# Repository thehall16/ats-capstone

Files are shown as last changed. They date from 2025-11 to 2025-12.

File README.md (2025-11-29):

# ats-capstone

11/29/2025
still need to figure out what LCD to use./ Display (maybe LCD maybe a Uart serial port connection)

Moved Firmware to Keil to easily use stm32cubemx for hal librarys and pin configuration.

Getting accurate readings from ZMPT101B display currently via uart and puTTY terminal.

Daughter board is in waiting on one componet to fully assemble

Reworking main PCB may use nucleo board instead of standalone mcu due to time constraint
aswell as code being formatted for the nucleo currently.

May need a new 12v power supply the cheap ups scares me.

We're gonna need a bigger boat (AC side housing for isolation).

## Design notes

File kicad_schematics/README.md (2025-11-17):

Folder containing KiCad schematics and PCB design

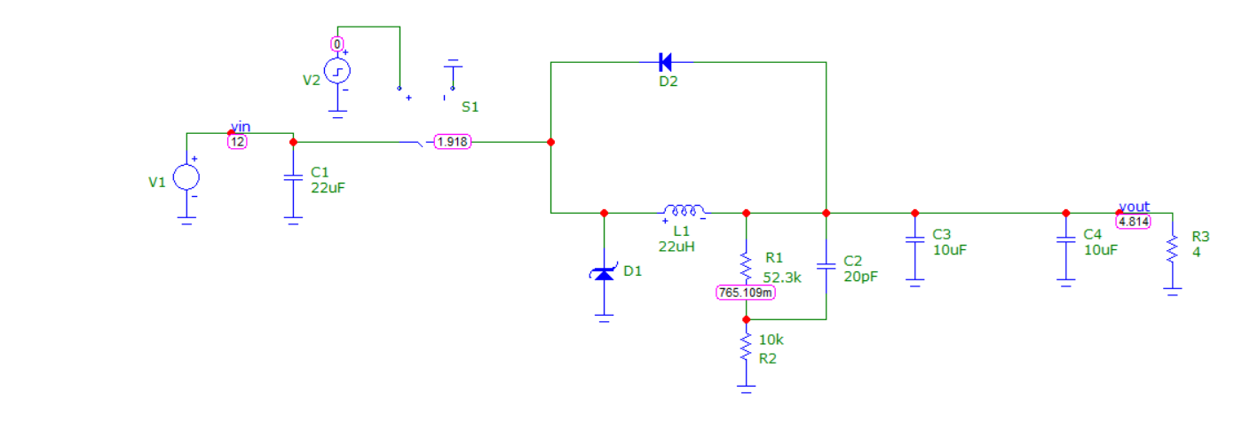
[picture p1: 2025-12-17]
bucksimsche.png

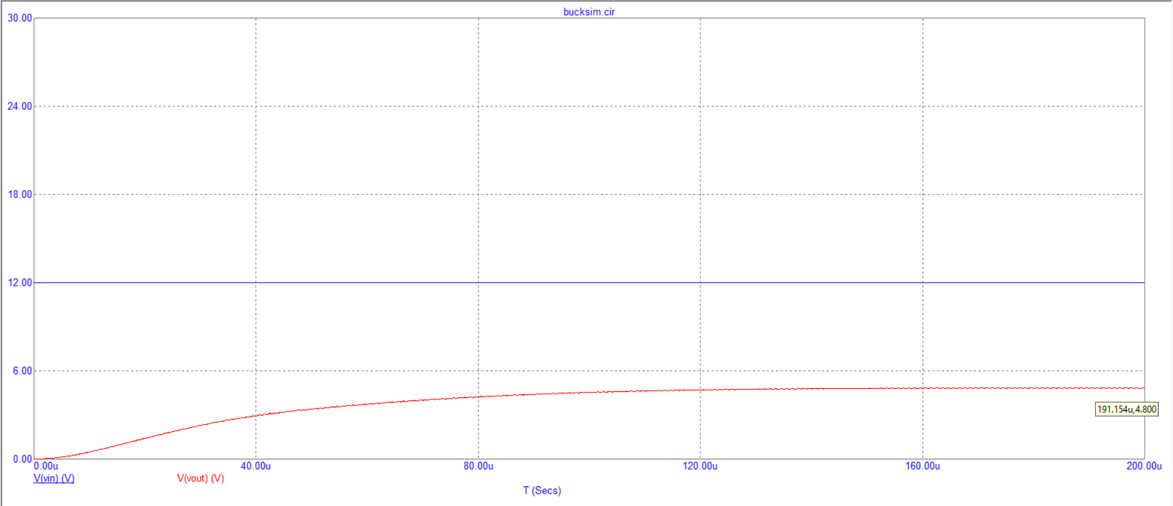
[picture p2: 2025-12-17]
bucksim.png

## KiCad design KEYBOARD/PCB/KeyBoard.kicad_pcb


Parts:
A1: RaspberryPi_Pico; RaspberryPi_Pico_Common_Unspecified
D1, D2, D3, D4, D5, D6, D7, D8, D9, D10, D11, D12, D13, D14, D15, D16, D17, D18, D19, D20, D21, D22, D23, D24, D25, D26, D27, D28, D29, D30, D31, D32, D33, D34, D35, D36, D37, D38, D39, D40, D41, D42, D43, D44, D45, D46, D47, D48, D49, D50, D51, D52, D53, D54, D55, D56, D57, D58, D59, D60, D61: 1N4148; D_DO-35_SOD27_P7.62mm_Horizontal
S1: MX_stab; STAB_MX_2u
S2, S3: MX_stab; STAB_MX_2.25u
S4: MX_stab; STAB_MX_2.75u
S5: MX_stab; STAB_MX_6.25u
SW1, SW2, SW3, SW4, SW5, SW6, SW7, SW8, SW9, SW10, SW11, SW12, SW13, SW16, SW17, SW18, SW19, SW20, SW21, SW22, SW23, SW24, SW25, SW26, SW27, SW30, SW31, SW32, SW33, SW34, SW35, SW36, SW37, SW38, SW39, SW40, SW51, SW52, SW53, SW54, SW55, SW56, SW57, SW58, SW59, SW60: SW_Push; SW_Cherry_MX_1.00u_PCB
SW14: SW_Push; SW_Cherry_MX_2.00u_PCB
SW15: SW_Push; SW_Cherry_MX_1.50u_PCB
SW28: SW_Push; SW_Cherry_MX_1.50u_Plate
SW29: SW_Push; SW_Cherry_MX_1.75u_PCB
SW41, SW50: SW_Push; SW_Cherry_MX_2.25u_PCB
SW42, SW43, SW44, SW46, SW48, SW49: SW_Push; SW_Cherry_MX_1.25u_PCB
SW45: SW_Push; SW_Cherry_MX_6.25u_PCB
SW47: SW_Push; SW_Cherry_MX_1.25u_Plate
SW61: SW_Push; SW_Cherry_MX_2.75u_PCB
SW62, SW63: RotaryEncoder_Switch_MP; RotaryEncoder_Alps_EC11E-Switch_Vertical_H20mm

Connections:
A1: A1.27 (GPIO21), SW62.A
A2: A1.32 (GPIO27_ADC1), SW63.A
B1: A1.29 (GPIO22), SW62.B
B2: A1.34 (GPIO28_ADC2), SW63.B
C0: A1.10 (GPIO7), SW1.1, SW15.1, SW29.1, SW42.1, SW50.1
C1: A1.11 (GPIO8), SW2.1, SW16.1, SW30.1, SW43.1, SW51.1
C2: A1.12 (GPIO9), SW3.1, SW17.1, SW31.1, SW44.1, SW52.1
C3: A1.14 (GPIO10), SW4.1, SW18.1, SW32.1, SW53.1
C4: A1.15 (GPIO11), SW5.1, SW19.1, SW33.1, SW54.1
C5: A1.16 (GPIO12), SW6.1, SW20.1, SW34.1, SW45.1, SW55.1
C6: A1.17 (GPIO13), SW7.1, SW21.1, SW35.1, SW56.1
C7: A1.19 (GPIO14), SW8.1, SW22.1, SW36.1, SW57.1
C8: A1.20 (GPIO15), SW9.1, SW23.1, SW37.1, SW46.1, SW58.1
C9: A1.21 (GPIO16), SW10.1, SW24.1, SW38.1, SW47.1, SW59.1
C10: A1.22 (GPIO17), SW11.1, SW25.1, SW39.1, SW48.1, SW60.1
C11: A1.24 (GPIO18), SW12.1, SW26.1, SW40.1, SW49.1, SW61.1
C12: A1.25 (GPIO19), SW13.1, SW27.1, SW41.1
C13: A1.26 (GPIO20), SW14.1, SW28.1
GND: A1.33 (AGND), SW62.C, SW62.S2, SW63.C, SW63.S2
unnamed: A1.3 (GND), A1.8 (GND), A1.13 (GND), A1.18 (GND), A1.23 (GND), A1.28 (GND), A1.38 (GND)
unnamed: D1.2 (A), SW1.2
unnamed: D2.2 (A), SW2.2
unnamed: D3.2 (A), SW3.2
unnamed: D4.2 (A), SW4.2
unnamed: D5.2 (A), SW5.2
unnamed: D6.2 (A), SW6.2
unnamed: D7.2 (A), SW7.2
unnamed: D8.2 (A), SW8.2
unnamed: D9.2 (A), SW9.2
unnamed: D10.2 (A), SW10.2
unnamed: D11.2 (A), SW11.2
unnamed: D12.2 (A), SW12.2
unnamed: D13.2 (A), SW13.2
unnamed: D14.2 (A), SW14.2
unnamed: D15.2 (A), SW15.2
unnamed: D16.2 (A), SW16.2
unnamed: D17.2 (A), SW17.2
unnamed: D18.2 (A), SW18.2
unnamed: D19.2 (A), SW19.2
unnamed: D20.2 (A), SW20.2
unnamed: D21.2 (A), SW21.2
unnamed: D22.2 (A), SW22.2
unnamed: D23.2 (A), SW23.2
unnamed: D24.2 (A), SW24.2
unnamed: D25.2 (A), SW25.2
unnamed: D26.2 (A), SW26.2
unnamed: D27.2 (A), SW27.2
unnamed: D28.2 (A), SW28.2
unnamed: D29.2 (A), SW29.2
unnamed: D30.2 (A), SW30.2
unnamed: D31.2 (A), SW31.2
unnamed: D32.2 (A), SW32.2
unnamed: D33.2 (A), SW33.2
unnamed: D34.2 (A), SW34.2
unnamed: D35.2 (A), SW35.2
unnamed: D36.2 (A), SW36.2
unnamed: D37.2 (A), SW37.2
unnamed: D38.2 (A), SW38.2
unnamed: D39.2 (A), SW39.2
unnamed: D40.2 (A), SW40.2
unnamed: D41.2 (A), SW41.2
unnamed: D42.2 (A), SW42.2
unnamed: D43.2 (A), SW43.2
unnamed: D44.2 (A), SW44.2
unnamed: D45.2 (A), SW45.2
unnamed: D46.2 (A), SW46.2
unnamed: D47.2 (A), SW47.2
unnamed: D48.2 (A), SW48.2
unnamed: D49.2 (A), SW49.2
unnamed: D50.2 (A), SW50.2
unnamed: D51.2 (A), SW51.2
unnamed: D52.2 (A), SW52.2
unnamed: D53.2 (A), SW53.2
unnamed: D54.2 (A), SW54.2
unnamed: D55.2 (A), SW55.2
unnamed: D56.2 (A), SW56.2
unnamed: D57.2 (A), SW57.2
unnamed: D58.2 (A), SW58.2
unnamed: D59.2 (A), SW59.2
unnamed: D60.2 (A), SW60.2
unnamed: D61.2 (A), SW61.2
R0: A1.4 (GPIO2), D1.1 (K), D2.1 (K), D3.1 (K), D4.1 (K), D5.1 (K), D6.1 (K), D7.1 (K), D8.1 (K), D9.1 (K), D10.1 (K), D11.1 (K), D12.1 (K), D13.1 (K), D14.1 (K)
R1: A1.5 (GPIO3), D15.1 (K), D16.1 (K), D17.1 (K), D18.1 (K), D19.1 (K), D20.1 (K), D21.1 (K), D22.1 (K), D23.1 (K), D24.1 (K), D25.1 (K), D26.1 (K), D27.1 (K), D28.1 (K)
R2: A1.6 (GPIO4), D29.1 (K), D30.1 (K), D31.1 (K), D32.1 (K), D33.1 (K), D34.1 (K), D35.1 (K), D36.1 (K), D37.1 (K), D38.1 (K), D39.1 (K), D40.1 (K), D41.1 (K)
R3: A1.7 (GPIO5), D50.1 (K), D51.1 (K), D52.1 (K), D53.1 (K), D54.1 (K), D55.1 (K), D56.1 (K), D57.1 (K), D58.1 (K), D59.1 (K), D60.1 (K), D61.1 (K)
R4: A1.9 (GPIO6), D42.1 (K), D43.1 (K), D44.1 (K), D45.1 (K), D46.1 (K), D47.1 (K), D48.1 (K), D49.1 (K)
S1: A1.31 (GPIO26_ADC0), SW62.S1
S2: A1.2 (GPIO1), SW63.S1



Board: 2 copper layers, 321.0 x 101.0 mm, 130 parts (61 on the bottom side), 88 nets.

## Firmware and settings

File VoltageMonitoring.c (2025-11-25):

// Voltage Monitoring 
// MCU: STM32C031K6T6
// Sensor: ZMPT101B (with adjustable potentiometer)
// Author: Spencer Grow

#include <stdio.h>
#include <math.h>
#include "stm32c0xx_hal.h"
#include "generator.h"
#include "Display.h"

// Voltage thresholds
float low_voltage  = 86.0f;     // Minimum acceptable AC voltage (RMS)
float high_voltage = 128.0f;    // Maximum acceptable AC voltage (RMS)

// GPIO Port
#define RELAY_PORT GPIOA

// Relay Pins
#define MAIN_SSR_PIN       GPIO_PIN_1
#define BACKUP_SSR_PIN     GPIO_PIN_2
#define SPDT_PIN           GPIO_PIN_6

// LED indicator pins (GEN steps)
#define CHOKE_LED_PIN      GPIO_PIN_3
#define START_LED_PIN      GPIO_PIN_4
#define RUN_LED_PIN        GPIO_PIN_5

// Delay before switching SPDT after SSR changes
#define SAFETY_DELAY_MS 300

// Function prototypes
ADC_HandleTypeDef hadc1;
float Read_Voltage_RMS(void);

typedef enum {
    SOURCE_MAIN,
    SOURCE_BACKUP
} PowerSource;

PowerSource current_source = SOURCE_MAIN;  // Assume main AC on startup

void SystemClock_Config(void);  // Provided by CubeIDE autocode
void MX_GPIO_Init(void);
void MX_ADC1_Init(void);


//MAIN PROGRAM
int main(void)
{
    HAL_Init();
    SystemClock_Config();
    MX_GPIO_Init();
    MX_ADC1_Init();
    display_init();              // Initialize 7-segment Display

    while (1)
    {
        // Read RMS voltage
        float voltage = Read_Voltage_RMS();

        // Update 7-segment display
        display_voltage(voltage);

        // NORMAL GRID OK 
        if (voltage >= low_voltage && voltage <= high_voltage)
        {
            if (current_source != SOURCE_MAIN)
            {
                // Turn off backup SSR
                HAL_GPIO_WritePin(RELAY_PORT, BACKUP_SSR_PIN, GPIO_PIN_RESET);

                // Stop generator sequence
                generator_stop();

                HAL_Delay(SAFETY_DELAY_MS);

                // Switch SPDT to MAIN
                HAL_GPIO_WritePin(RELAY_PORT, SPDT_PIN, GPIO_PIN_RESET);

                // Enable main SSR
                HAL_GPIO_WritePin(RELAY_PORT, MAIN_SSR_PIN, GPIO_PIN_SET);

                current_source = SOURCE_MAIN;
            }
        }

        // GRID OUT OF RANGE
        else
        {
            if (current_source != SOURCE_BACKUP)
            {
                // Turn off main SSR
                HAL_GPIO_WritePin(RELAY_PORT, MAIN_SSR_PIN, GPIO_PIN_RESET);

                // Start generator sequence
                generator_startup_sequence();

                HAL_Delay(SAFETY_DELAY_MS);

                // Switch SPDT to BACKUP
                HAL_GPIO_WritePin(RELAY_PORT, SPDT_PIN, GPIO_PIN_SET);

                // Turn on backup SSR
                HAL_GPIO_WritePin(RELAY_PORT, BACKUP_SSR_PIN, GPIO_PIN_SET);

                current_source = SOURCE_BACKUP;
            }
        }

        HAL_Delay(200); // main loop delay
    }
}


// RMS Voltage Measurement
float Read_Voltage_RMS(void)
{
    const uint16_t samples = 200;
    const float ADC_MID = 2048.0f;  // 12-bit midpoint
    float sum_sq = 0.0f;

    for (uint16_t i = 0; i < samples; i++)
    {
        HAL_ADC_Start(&hadc1);
        HAL_ADC_PollForConversion(&hadc1, HAL_MAX_DELAY);
        uint16_t adc_val = HAL_ADC_GetValue(&hadc1);
        HAL_ADC_Stop(&hadc1);

        float centered = (float)adc_val - ADC_MID;  // remove DC bias
        sum_sq += centered * centered;
    }

    float adc_rms = sqrtf(sum_sq / samples);

    // Convert ADC RMS → Volts RMS (TEMP FACTOR)
    float sensor_voltage = (adc_rms * 3.3f) / 4096.0f;

    // ZMPT101B calibration multiplier — adjusted via board potentiometer later
    float voltage_rms = sensor_voltage * 100.0f;

    return voltage_rms;
}


// GPIO Initialization
void MX_GPIO_Init(void)
{
    __HAL_RCC_GPIOA_CLK_ENABLE();

    GPIO_InitTypeDef GPIO_InitStruct = {0};

    // ADC pin (PA0)
    GPIO_InitStruct.Pin = GPIO_PIN_0;
    GPIO_InitStruct.Mode = GPIO_MODE_ANALOG;
    GPIO_InitStruct.Pull  = GPIO_NOPULL;
    HAL_GPIO_Init(GPIOA, &GPIO_InitStruct);

    // Output pins: SSRs + SPDT + LED indicators
    GPIO_InitStruct.Pin =
          MAIN_SSR_PIN
        | BACKUP_SSR_PIN
        | SPDT_PIN
        | CHOKE_LED_PIN
        | START_LED_PIN
        | RUN_LED_PIN;

    GPIO_InitStruct.Mode  = GPIO_MODE_OUTPUT_PP;
    GPIO_InitStruct.Pull  = GPIO_NOPULL;
    GPIO_InitStruct.Speed = GPIO_SPEED_FREQ_LOW;
    HAL_GPIO_Init(GPIOA, &GPIO_InitStruct);
}


// ADC Initialization
void MX_ADC1_Init(void)
{
    __HAL_RCC_ADC1_CLK_ENABLE();

    hadc1.Instance = ADC1;
    hadc1.Init.ClockPrescaler        = ADC_CLOCK_SYNC_PCLK_DIV4;
    hadc1.Init.Resolution            = ADC_RESOLUTION_12B;
    hadc1.Init.DataAlign             = ADC_DATAALIGN_RIGHT;
    hadc1.Init.ScanConvMode          = ADC_SCAN_DISABLE;
    hadc1.Init.EOCSelection          = ADC_EOC_SINGLE_CONV;
    hadc1.Init.ContinuousConvMode    = DISABLE;
    hadc1.Init.NbrOfConversion       = 1;
    hadc1.Init.ExternalTrigConv      = ADC_SOFTWARE_START;

    HAL_ADC_Init(&hadc1);

    ADC_ChannelConfTypeDef sConfig = {0};
    sConfig.Channel      = ADC_CHANNEL_0;   // PA0
    sConfig.Rank         = ADC_REGULAR_RANK_1;
    sConfig.SamplingTime = ADC_SAMPLETIME_71CYCLES_5;

    HAL_ADC_ConfigChannel(&hadc1, &sConfig);
}

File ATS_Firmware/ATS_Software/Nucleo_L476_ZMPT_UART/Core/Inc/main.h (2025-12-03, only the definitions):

#define B1_Pin GPIO_PIN_13
#define B1_GPIO_Port GPIOC
#define USART_TX_Pin GPIO_PIN_2
#define USART_TX_GPIO_Port GPIOA
#define USART_RX_Pin GPIO_PIN_3
#define USART_RX_GPIO_Port GPIOA
#define LD2_Pin GPIO_PIN_5
#define LD2_GPIO_Port GPIOA
#define LED_PWR_Pin GPIO_PIN_0
#define LED_PWR_GPIO_Port GPIOB
#define LED_S1_Pin GPIO_PIN_1
#define LED_S1_GPIO_Port GPIOB
#define LED_S2_Pin GPIO_PIN_2
#define LED_S2_GPIO_Port GPIOB
#define LED_S3_Pin GPIO_PIN_10
#define LED_S3_GPIO_Port GPIOB
#define RELAY_MAIN_Pin GPIO_PIN_8
#define RELAY_MAIN_GPIO_Port GPIOA
#define RELAY_GEN_Pin GPIO_PIN_9
#define RELAY_GEN_GPIO_Port GPIOA
#define RELAY_TRANSFER_Pin GPIO_PIN_10
#define RELAY_TRANSFER_GPIO_Port GPIOA
#define TMS_Pin GPIO_PIN_13
#define TMS_GPIO_Port GPIOA
#define TCK_Pin GPIO_PIN_14
#define TCK_GPIO_Port GPIOA
#define SWO_Pin GPIO_PIN_3
#define SWO_GPIO_Port GPIOB

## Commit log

2025-10-30 Voltage Monitoring Initial Setup
    Added VoltageMonitoring.c, generartor.h, and generator.c, for VoltageMonitoring.c included basic overview and layout for voltage monitoring on inputs.
2025-10-30 clean up/Flush out
    Added Display.c for possible LCD display. started setting up gen sim. added space for secondary function in VoltageMonitoring.c
2025-11-12 Read_Voltage_RMS function
    Code added for converting the signal from ADC to an RMS voltage value that will be displayed, added comments to show what is still needed. Also started on the generator simulation.
2025-11-17 Add KiCad schematic V1
    [mcp16331_buck.kicad_sch, mcp16331_buck_v9.kicad_sch, test.kicad_pcb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]
2025-11-24 qualifiers preparations
    display will now be a seven segment display. fixed/ expanded old code
    [Display.c, VoltageMonitoring.c, generator.c]
2025-11-25 ADC init and GPIO init beofre moving files to stm32Cube
2025-11-29 hooray! ( initial ZMPT101B readings)
    ZMPT101B readings recived. currently displays current voltage from the ZMPT101B module output, displays via uart, puTTY config: serial, COM3 (for me) and speed 115200. currently only displays dc offs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
2025-11-29 ZMPT101B working
    Using puTTy to display line voltage give fairly accurate voltage.
2025-11-29 Accuracy fix
    fixed some redundancies, code is fairly accurate within +-2V between ~40-130V
2025-11-29 updated readme
    updated read me with current plans/progress. (idk why closing Keil updates the project here)
2025-12-03 Reformatting Block Demos
    re formatted to have demos to test different function of code in the same file. got relay test demo to work working on combining voltage reading and relays switching currently.
2025-12-03 relay+voltage demo
    got relay demo and voltage reading demo to work together.
2025-12-04 full demo working
    patchwork demo code is working, need to ensure gen is on i.e. LED_S3 is on before Transfer relay switches
2025-12-04 fixed visuals and final demo
    now works 90% of cases, I believe there are errors if voltage returns to normal range before gen sim has finished.
2025-12-04 ATS_to_GEN
    updated the code so all relays are open when gen is starting up to ensure load will never connect to a dead source. other then switching from a "dead" main
2025-12-13 under 20v
    zmpt101b under 20v reads as 0v as at 0-20V accuracy is off by up to 8V, and voltage is negligible.
2025-12-16 fixed comments & checking eqs
    fixed / expanded comments, trying to remember how I calculate voltage as i have a lot of constants that have been changed and adjusted.
2026-02-27 replaced uart.c in wrong folder with header file
2026-02-27 moved Button LED demo to separate file to test modularization
2026-02-27 flashed to board

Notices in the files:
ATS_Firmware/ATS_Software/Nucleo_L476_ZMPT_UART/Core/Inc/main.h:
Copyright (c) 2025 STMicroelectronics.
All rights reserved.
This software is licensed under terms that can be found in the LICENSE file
